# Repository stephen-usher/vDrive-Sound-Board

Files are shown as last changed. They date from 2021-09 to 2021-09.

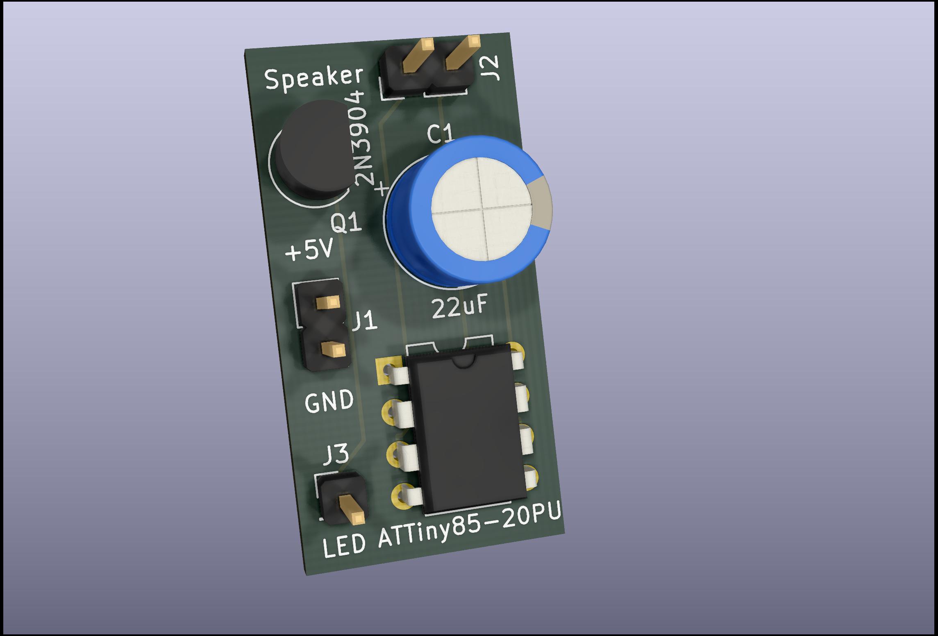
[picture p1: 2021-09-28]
vDrive-Sound-Board.jpg

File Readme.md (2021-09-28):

# vDrive Sound Board

This PCB uses an ATTiny85 microcontroller to play a digitised sound recording
of a Sinclair Microdrive on a speaker, controlled by the LED output on either
a vDriveZX or vDriveQL. The controller will start playing as soon as it gets
power, which is controlled using an NPN transistor. The capacitor is there to
make sure that any small power fluctuations don't cause the ATTiny85 to crash.

The sound playback code was originally written by David Johnson-Davies
(www.technoblogy.com) in 2017 and modified to add the Microdrive sound data
and set the correct playback speed.

See: http://www.technoblogy.com/show?QBB

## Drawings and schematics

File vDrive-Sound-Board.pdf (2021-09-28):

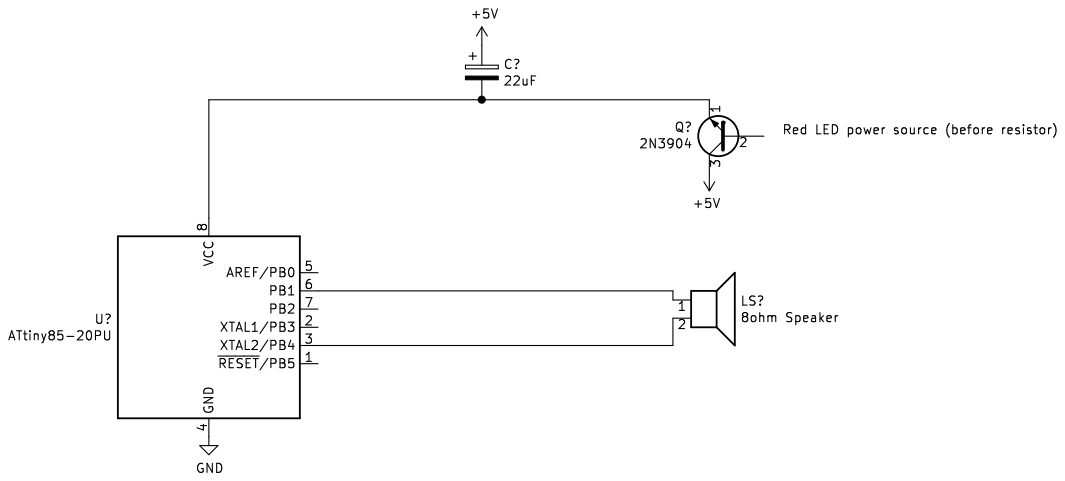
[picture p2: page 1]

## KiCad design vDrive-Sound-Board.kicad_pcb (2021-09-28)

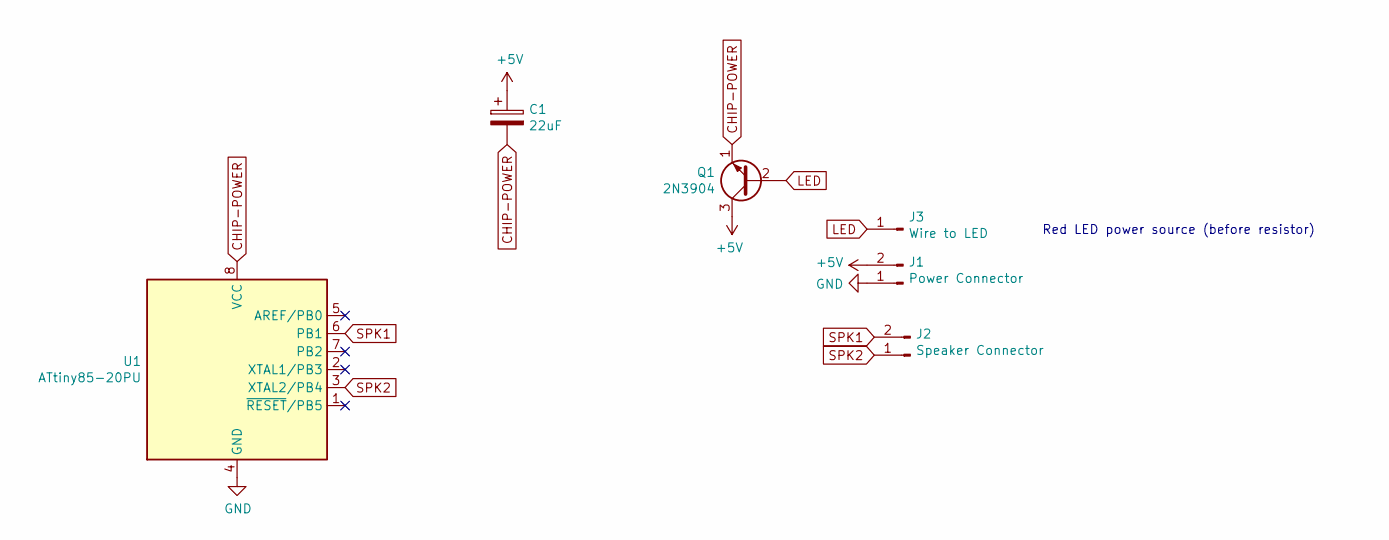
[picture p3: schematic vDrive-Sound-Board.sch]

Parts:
C1: 22uF; CP_Radial_D8.0mm_P2.50mm
J1: Power Connector; PinHeader_1x02_P2.54mm_Vertical
J2: Speaker Connector; PinHeader_1x02_P2.54mm_Vertical
J3: Wire to LED; PinHeader_1x01_P2.54mm_Vertical
Q1: 2N3904; TO-92_Inline
U1: ATtiny85-20PU; DIP-8_W7.62mm

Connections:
+5V: C1.1, J1.2, Q1.3 (C)
CHIP-POWER: C1.2, Q1.1 (E), U1.8 (VCC)
GND: J1.1, U1.4 (GND)
LED: J3.1, Q1.2 (B)
SPK1: J2.2, U1.6 (PB1)
SPK2: J2.1, U1.3 (XTAL2/PB4)

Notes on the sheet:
Red LED power source (before resistor)

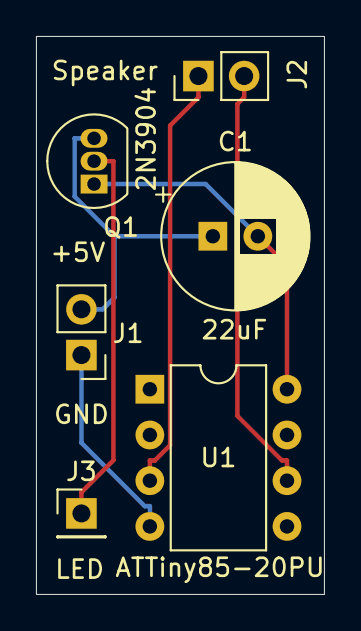
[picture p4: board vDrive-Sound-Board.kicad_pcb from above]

Board: 2 copper layers, 16.0 x 31.0 mm, 6 parts (0 on the bottom side), 6 nets.

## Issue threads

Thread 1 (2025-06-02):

Typping symbol mistake?

Silveriomrs, 2025-06-02:
Hello Stephen,
Thanks for sharing your project.

I may be wrong,
Is it right that the capacitor is between +5v and +5v? Should it not be between +5v and GND for decoupling and avoiding fluctuation of the power?

Thank you

Silveriomrs, 2025-06-02:
Thank you Stephen,
I will study it out with oscilloscope.
What you describe makes sense.

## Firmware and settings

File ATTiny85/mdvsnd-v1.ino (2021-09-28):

/* Audio Sample Player v2

   David Johnson-Davies - www.technoblogy.com - 23rd October 2017
   ATtiny85 @ 8 MHz (internal oscillator; BOD disabled)
      
   CC BY 4.0
   Licensed under a Creative Commons Attribution 4.0 International license: 
   http://creativecommons.org/licenses/by/4.0/
*/

/* Direct-coupled capacitorless output */

#include <avr/pgmspace.h>
#include <avr/sleep.h>
#define adc_disable()  (ADCSRA &= ~(1<<ADEN))

// Audio encoded as unsigned 8-bit, 8kHz sampling rate
const uint8_t mdvsnd_wav[] PROGMEM = {
  0x52, 0x49, 0x46, 0x46, 0xa2, 0x0a, 0x00, 0x00, 0x57, 0x41, 0x56, 0x45,
  0x66, 0x6d, 0x74, 0x20, 0x10, 0x00, 0x00, 0x00, 0x01, 0x00, 0x01, 0x00,
  0x40, 0x1f, 0x00, 0x00, 0x40, 0x1f, 0x00, 0x00, 0x01, 0x00, 0x08, 0x00,
  0x64, 0x61, 0x74, 0x61, 0x7e, 0x0a, 0x00, 0x00, 0xc3, 0xc2, 0x95, 0x95,
  0x68, 0x52, 0x7f, 0x95, 0x95, 0xc2, 0xac, 0x95, 0x52, 0x51, 0x69, 0x95,
  0x95, 0x96, 0xab, 0x69, 0x68, 0xac, 0x51, 0x00, 0x51, 0x7f, 0x52, 0x3b,
  0x67, 0x52, 0x7e, 0x96, 0x50, 0x25, 0x68, 0x95, 0xac, 0xc2, 0xad, 0xac,
  0xc2, 0x7f, 0x3b, 0x51, 0xc3, 0xab, 0x69, 0x67, 0x69, 0x7f, 0xd8, 0xc3,
  0x96, 0x3a, 0x0f, 0x50, 0xad, 0xac, 0x7e, 0x69, 0x52, 0x7e, 0x68, 0x7f,
  0xac, 0x51, 0x0e, 0x51, 0x96, 0xda, 0xd9, 0x7e, 0xc2, 0x95, 0x69, 0x67,
  0x52, 0x52, 0x7f, 0xc3, 0xfe, 0xac, 0x69, 0xab, 0x69, 0x51, 0x68, 0x7f,
  0x7e, 0x96, 0x7f, 0x95, 0xc3, 0x94, 0x69, 0x7e, 0x68, 0x24, 0x0e, 0x25,
  0x51, 0x51, 0x51, 0x68, 0x68, 0x68, 0x68, 0xac, 0xac, 0xac, 0xc3, 0xad,
  0x7e, 0xad, 0x7f, 0x52, 0x51, 0xac, 0xc3, 0xab, 0x69, 0x50, 0x7f, 0xac,
  0x7e, 0x52, 0x3a, 0x52, 0x50, 0x52, 0x96, 0xab, 0x52, 0x3a, 0xad, 0x7f,
  0x3c, 0x80, 0x94, 0x69, 0x68, 0x68, 0x7f, 0x95, 0xac, 0xc2, 0x7f, 0x7f,
  0x67, 0x52, 0xab, 0xda, 0xc1, 0x96, 0x69, 0x67, 0x69, 0x7e, 0xad, 0xd9,
  0xc2, 0x7f, 0x95, 0x3c, 0x67, 0x96, 0x3a, 0x3c, 0x50, 0x52, 0x96, 0x50,
  0x52, 0x7d, 0x69, 0x69, 0x7d, 0xad, 0x7e, 0x7f, 0x7e, 0x7f, 0xac, 0x95,
  0xc2, 0xda, 0x67, 0x69, 0x68, 0x7f, 0x95, 0x51, 0x51, 0x68, 0x7e, 0xda,
  0xd8, 0x96, 0x52, 0x68, 0x95, 0x68, 0x95, 0x95, 0x51, 0x51, 0x68, 0x68,
  0x69, 0x51, 0x68, 0x3b, 0x52, 0x80, 0x94, 0x96, 0x95, 0x7f, 0x96, 0x67,
  0x69, 0x51, 0x69, 0xac, 0xc2, 0xac, 0xac, 0x96, 0x80, 0x7e, 0x3c, 0x69,
  0x95, 0x96, 0xac, 0x7e, 0x80, 0xc1, 0xc3, 0x3a, 0x00, 0x0f, 0x25, 0x69,
  0x69, 0x67, 0x96, 0x7e, 0x52, 0x7f, 0xac, 0xac, 0x69, 0x67, 0x96, 0x95,
  0xc2, 0xd9, 0xd9, 0xad, 0x69, 0x96, 0x96, 0x95, 0x51, 0x3b, 0x68, 0x7f,
  0x7f, 0x95, 0x69, 0x69, 0xad, 0xc3, 0xad, 0x7e, 0x69, 0x3b, 0x7f, 0x52,
  0x3b, 0x3b, 0x3b, 0x7f, 0x7e, 0x95, 0xad, 0xc2, 0x68, 0x95, 0xad, 0x67,
  0x52, 0x50, 0x69, 0x7f, 0xc2, 0xd9, 0xad, 0x7f, 0x7f, 0x52, 0x50, 0x80,
  0xac, 0x7f, 0x69, 0x95, 0xac, 0x95, 0x68, 0x3c, 0x95, 0x95, 0x3b, 0x0f,
  0x23, 0x52, 0x50, 0x80, 0x7e, 0x96, 0x69, 0x67, 0xc3, 0xc1, 0x80, 0xac,
  0xd9, 0xd9, 0xc3, 0x68, 0x69, 0xac, 0xad, 0xab, 0x96, 0x3b, 0x52, 0x7f,
  0xab, 0xc3, 0x68, 0x3c, 0x51, 0x80, 0x95, 0x69, 0x7e, 0x95, 0x68, 0xac,
  0xd9, 0x95, 0x68, 0x51, 0x25, 0x3b, 0x7f, 0xc3, 0xd8, 0xc3, 0xc2, 0x95,
  0x80, 0x51, 0x69, 0x80, 0xac, 0xd9, 0xd9, 0x80, 0x51, 0x3c, 0x51, 0x7f,
  0xc3, 0xac, 0x69, 0x51, 0x68, 0x7f, 0x69, 0x50, 0x69, 0x51, 0x3b, 0x52,
  0x50, 0x25, 0x50, 0x69, 0x67, 0x69, 0x51, 0x68, 0x80, 0x95, 0xc3, 0xac,
  0x7f, 0xc3, 0xad, 0x51, 0x69, 0x67, 0xc3, 0xd8, 0x7e, 0x7f, 0x52, 0x7f,
  0xad, 0xda, 0xd9, 0x51, 0x24, 0x68, 0x80, 0x94, 0xad, 0x51, 0x95, 0xc2,
  0x51, 0x24, 0x51, 0x7f, 0x7f, 0x67, 0xad, 0xd8, 0x96, 0x95, 0xc2, 0x96,
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
};
unsigned int mdvsnd_wav_len = 2730;



unsigned int p = 0;

void setup () {
  // Enable 64 MHz PLL and use as source for Timer1
  PLLCSR = 1<<PCKE | 1<<PLLE;     
 
  // Set up Timer/Counter1 for PWM output
  TIMSK = 0;                              // Timer interrupts OFF
  TCCR1 = 1<<PWM1A | 2<<COM1A0 | 1<<CS10; // PWM A, clear on match, 1:1 prescale
  GTCCR = 1<<PWM1B | 2<<COM1B0;           // PWM B, clear on match
  OCR1A = 128; OCR1B = 128;               // 50% duty at start

  // Set up Timer/Counter0 for 8kHz interrupt to output samples.
  TCCR0A = 3<<WGM00;                      // Fast PWM
  TCCR0B = 1<<WGM02 | 2<<CS00;            // 1/8 prescale
  TIMSK = 1<<OCIE0A;                      // Enable compare match
  OCR0A = 28;                            // Divide by 1000 was 124

  set_sleep_mode(SLEEP_MODE_PWR_DOWN);
  pinMode(4, OUTPUT);
  pinMode(1, OUTPUT);
}

void loop () { }

// Sample interrupt
ISR (TIMER0_COMPA_vect) {
  char sample = pgm_read_byte(&mdvsnd_wav[p++]);
  OCR1A = sample; OCR1B = sample ^ 255;
  // End of data? Go to sleep
  if (p == mdvsnd_wav_len) {
    p = 0;
  }
}
